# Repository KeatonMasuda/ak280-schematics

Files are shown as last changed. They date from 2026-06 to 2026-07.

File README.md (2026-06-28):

# ak280-schematics

[Japanese README is here](README.ja.md)

This repository contains the schematic for the AK-280 audio amplifier purchased from Amazon, created by tracing the printed patterns and components. The schematic is created using KiCad.

<p align="center">
  <a href="images/ak280-schematic.pdf">
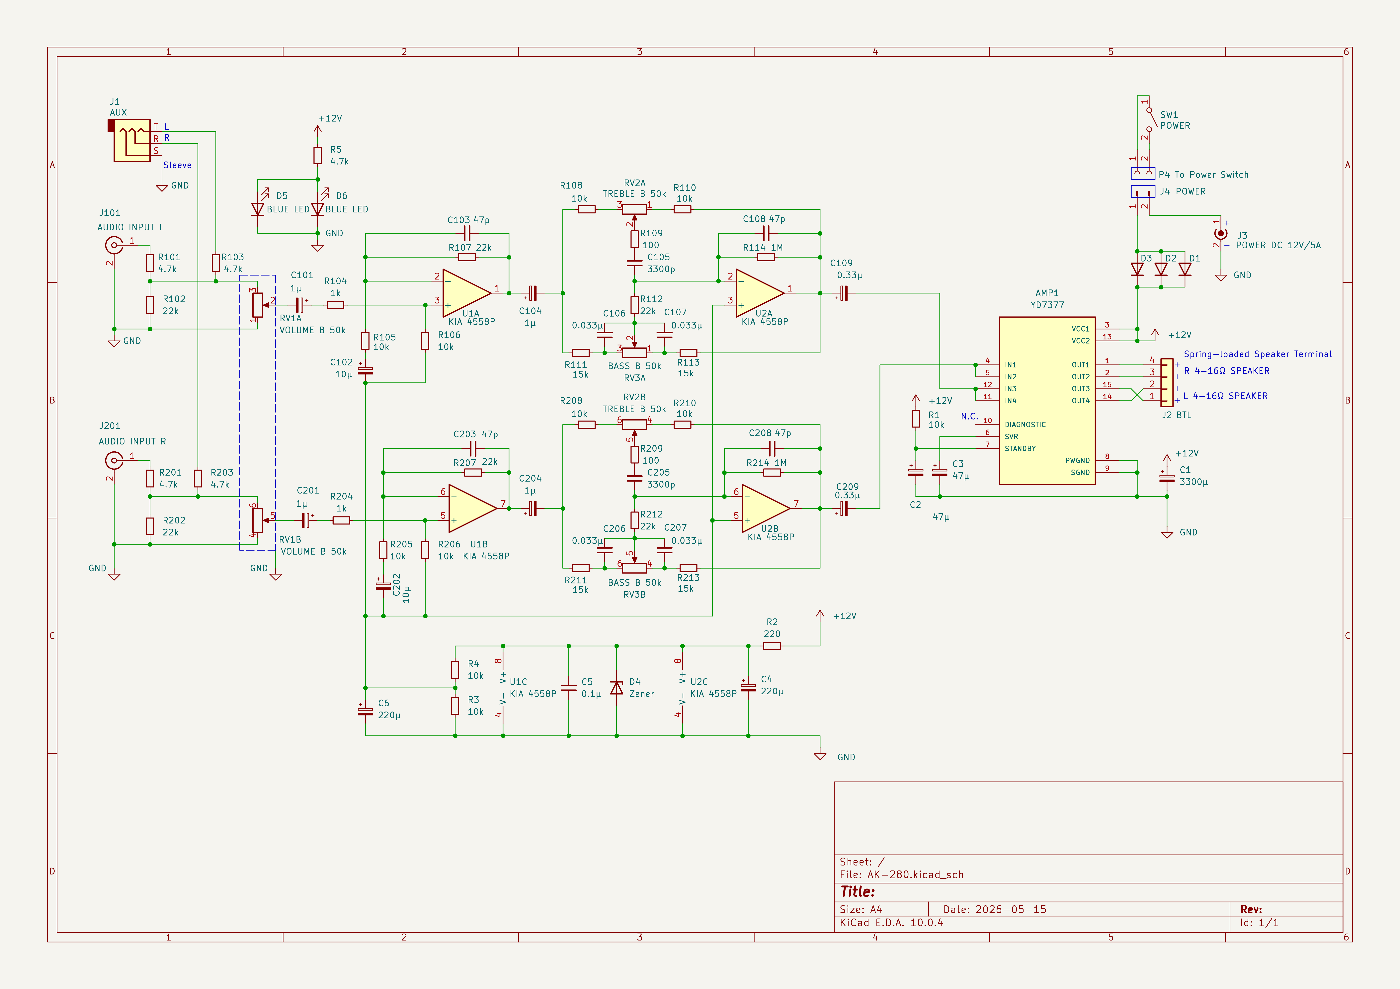
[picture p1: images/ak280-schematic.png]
    
  </a><br>
  Figure 1: AK-280 schematic(clock to PDF)
</p>

<table style="width: 100%; border: none;">
  <tr>
    <td style="width: 50%; text-align: center; border: none;">
      <br>
      Figure 2: AK-280 close-up
    </td>
    <td style="width: 50%; text-align: center; border: none;">
      <br>
      Figure 3: AK-280 SP system
    </td>
  </tr>
  <tr>
    <td style="width: 50%; text-align: center; border: none;">
      <br>
      Figure 4: PCB Component side with reference numbers
    </td>
    <td style="width: 50%; text-align: center; border: none;">
      <br>
      Figure 5: PCB Solder side with reference numbers
    </td>
  </tr>
  <tr>
    <td style="width: 50%; text-align: center; border: none;">
      <br>
      Figure 6: PCB Solder side with reference numbers (mirrored)
    </td>
    <td style="width: 50%; text-align: center; border: none;">
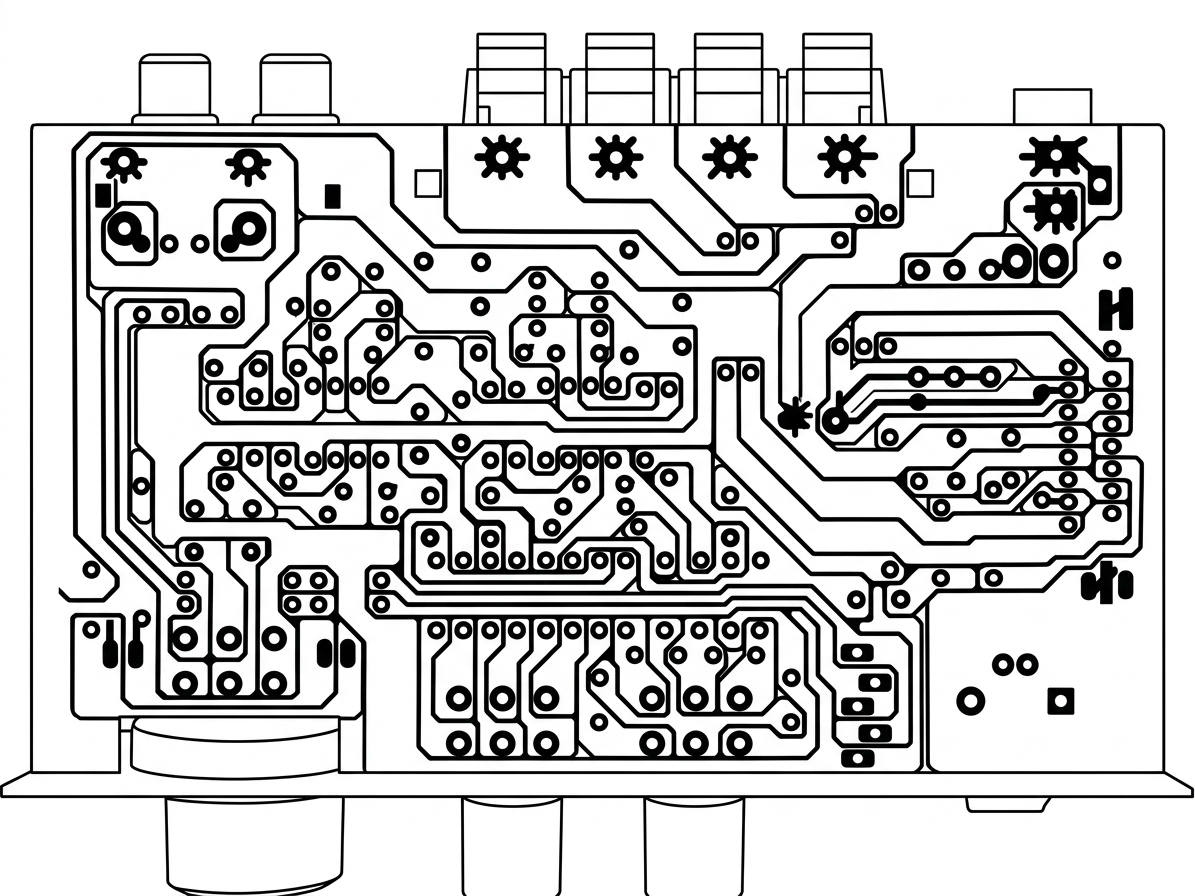
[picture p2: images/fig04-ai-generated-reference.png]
      <br>
      Figure 7: AI-generated reference
    </td>
  </tr>
</table>

## Project Objective
This project was created for personal hobby purposes only. There is no specific intended purpose or goal.

## Directory Structure

    ak280-schematics/
    ├── hardware/
    │   ├── AK-280.kicad_pro
    │   └── AK-280.kicad_sch
    ├── images/
    │   ├── ak280-photo.png
    │   ├── ak280-schematic.pdf
    │   ├── ak280-schematic.png
    │   ├── ak280-system-photo.png
    │   ├── fig01-topside-with-refno.png
    │   ├── fig01-topside-with-refno.zip
    │   ├── fig02-bottomside-with-refno-org.png
    │   ├── fig02-bottomside-with-refno-org.zip
    │   ├── fig03-bottomside-with-refno-mirror.png
    │   ├── fig03-bottomside-with-refno-mirror.zip
    │   └── fig04-ai-generated-reference.png
    ├── LICENSE
    ├── README.ja.md
    └── README.md

## File Descriptions

* **hardware/**: Contains all KiCad schematic files and design data.
* **images/**: Contains the following circuit diagrams and related reference materials:
    * **ak280-schematic.pdf**: Circuit schematic (PDF file)
    * **ak280-schematic.png**: Circuit schematic (PNG file)
    * **ak280-photo.png**: Close-up photo of AK-280
    * **ak280-system-photo.png**: AK-280 SP system photo
    * **fig01-topside-with-refno.png**: Top-side photo with circuit reference numbers (For viewing)
    * **fig01-topside-with-refno.zip**: Top-side photo with circuit reference numbers (GIMP source data)
    * **fig02-bottomside-with-refno-org.png**: Bottom-side photo with circuit reference numbers (Original, for viewing)
    * **fig02-bottomside-with-refno-org.zip**: Bottom-side photo with circuit reference numbers (Original, GIMP source data)
    * **fig03-bottomside-with-refno-mirror.png**: Bottom-side photo with circuit reference numbers (Mirrored, for viewing)
    * **fig03-bottomside-with-refno-mirror.zip**: Bottom-side photo with circuit reference numbers (Mirrored, GIMP source data)
    * **fig04-ai-generated-reference.png**: Pattern diagram generated by AI and verified by visual inspection.
* **LICENSE**: Project license information.
* **README.ja.md**: Detailed project description in Japanese.
* **README.md**: Detailed project description in English (this file).

## Environment
* **KiCad**: 10.0.4
* **GIMP**: 3.2.4

## Usage

* **View Schematic**: Refer to `images/ak280-schematic.pdf`.
* **View Component Reference Numbers**: Refer to `images/fig01-topside-with-refno.png` and `images/fig02-bottomside-with-refno-org.png`.
* **Edit Schematic**: Launch KiCad and open `hardware/AK-280.kicad_pro`.
* **Edit Component Reference Numbers**: Extract `images/fig01-topside-with-refno.zip`, `images/fig02-bottomside-with-refno-org.zip`, or `images/fig03-bottomside-with-refno-mirror.zip` and open them with GIMP.

## Disclaimer
The schematics in this repository were created based on visual inspection of the actual board . While every effort has been made to ensure accuracy, the integrity of the netlist is not 100% guaranteed. The author assumes no responsibility or liability for any damage, accidents, unforeseen malfunctions, or other losses resulting from the use of this data. Please use at your own risk.

## Acknowledgments
* The TDA7377 KiCad symbol used in this project is provided by Snapmagic (https://www.snapmagic.com/)

## License
This project is licensed under the MIT License. See the [LICENSE](LICENSE) file for details.

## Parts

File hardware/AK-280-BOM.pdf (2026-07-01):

AK-280

# ページ 1

Reference Qty MANUFACTURER | Value | Voltage Wattage Type
AMP1 | 1 | Wuxi Youda Electronics YD7377
C1 | 1 | 3300μ | 16V | Aluminum Electrolytic (Standard)
C2 | 1 | 47μ | 25V | Aluminum Electrolytic (Standard)
C3 | 1 | 47μ | 25V | Aluminum Electrolytic (Standard)
C4 | 1 | 220μ | 16V | Aluminum Electrolytic (Standard)
C5 | 1 | 0.1μ | | Ceramic Capacitor (X7R)
C6 | 1 | 220μ | 16V | Aluminum Electrolytic (Standard)
C101 | 1 | 1μ | 50V | Aluminum Electrolytic (Low ESR)
C102 | 1 | 10μ | 50V | Aluminum Electrolytic (Low ESR)
C103 | 1 | 47p | | Ceramic Capacitor (C0G)
C104 | 1 | 1μ | 50V | Aluminum Electrolytic (Low ESR)
C105 | 1 | 3300p | | Film Capacitor
C106 | 1 | 0.033μ | | Film Capacitor
C107 | 1 | 0.033μ | | Film Capacitor
C108 | 1 | 47p | | Ceramic Capacitor (C0G)
C109 | 1 | 0.33μ | 50V | Aluminum Electrolytic (Low ESR)
C201 | 1 | 1μ | 50V | Aluminum Electrolytic (Low ESR)
C202 | 1 | 10μ | 50V | Aluminum Electrolytic (Low ESR)
C203 | 1 | 47p | | Ceramic Capacitor (C0G)
C204 | 1 | 1μ | 50V | Aluminum Electrolytic (Low ESR)
C205 | 1 | 3300p | | Film Capacitor
C206 | 1 | 0.033μ | | Film Capacitor
C207 | 1 | 0.033μ | | Film Capacitor
C208 | 1 | 47p | | Ceramic Capacitor (C0G)
C209 | 1 | 0.33μ | 50V | Aluminum Electrolytic (Low ESR)
D1 | 1 | 1N5400
D2 | 1 | 1N5400
D3 | 1 | 1N5400
D4 | 1 | Zener | 9.1V
D5 | 1 | BLUE LED
D6 | 1 | BLUE LED
J1 | 1 | AUX
J2 | 1 | BTL

AK-280

# ページ

2

J3

1 | POWER DC 12V/5A
J4
1 | POWER
J101
1 | AUDIO INPUT L
J201
1 | AUDIO INPUT R
P4
1 | To Power Switch
R1
1 | 10k | 1/4W
R2
1 | 220 | 1/2W
R3
1 | 10k | 1/4W
R4
1 | 10k | 1/4W
R5
1 | 4.7k | 1/4W
R101
1 | 4.7k | 1/4W
R102
1 | 22k | 1/4W
R103
1 | 4.7k | 1/4W
R104
1 | 1k | 1/4W
R105
1 | 10k | 1/4W
R106
1 | 10k | 1/4W
R107
1 | 22k | 1/4W
R108
1 | 10k | 1/4W
R109
1 | 100 | 1/4W
R110
1 | 10k | 1/4W
R111
1 | 15k | 1/4W
R112
1 | 22k | 1/4W
R113
1 | 15k | 1/4W
R114
1 | 1M | 1/4W
R201
1 | 4.7k | 1/4W
R202
1 | 22k | 1/4W
R203
1 | 4.7k | 1/4W
R204
1 | 1k | 1/4W
R205
1 | 10k | 1/4W
R206
1 | 10k | 1/4W
R207
1 | 22k | 1/4W
R208
1 | 10k | 1/4W
R209
1 | 100 | 1/4W
R210
1 | 10k | 1/4W

AK-280

# ページ 3

R211 | 1 | 15k | 1/4W
R212 | 1 | 22k | 1/4W
R213 | 1 | 15k | 1/4W
R214 | 1 | 1M | 1/4W
RV1 | 1 | VOLUME B 50k
RV2 | 1 | TREBLE B 50k
RV3 | 1 | BASS B 50k
SW1 | 1 | POWER
U1 | 1 | Korea Electronics | KIA 4558P
U2 | 1 | Korea Electronics | KIA 4558P

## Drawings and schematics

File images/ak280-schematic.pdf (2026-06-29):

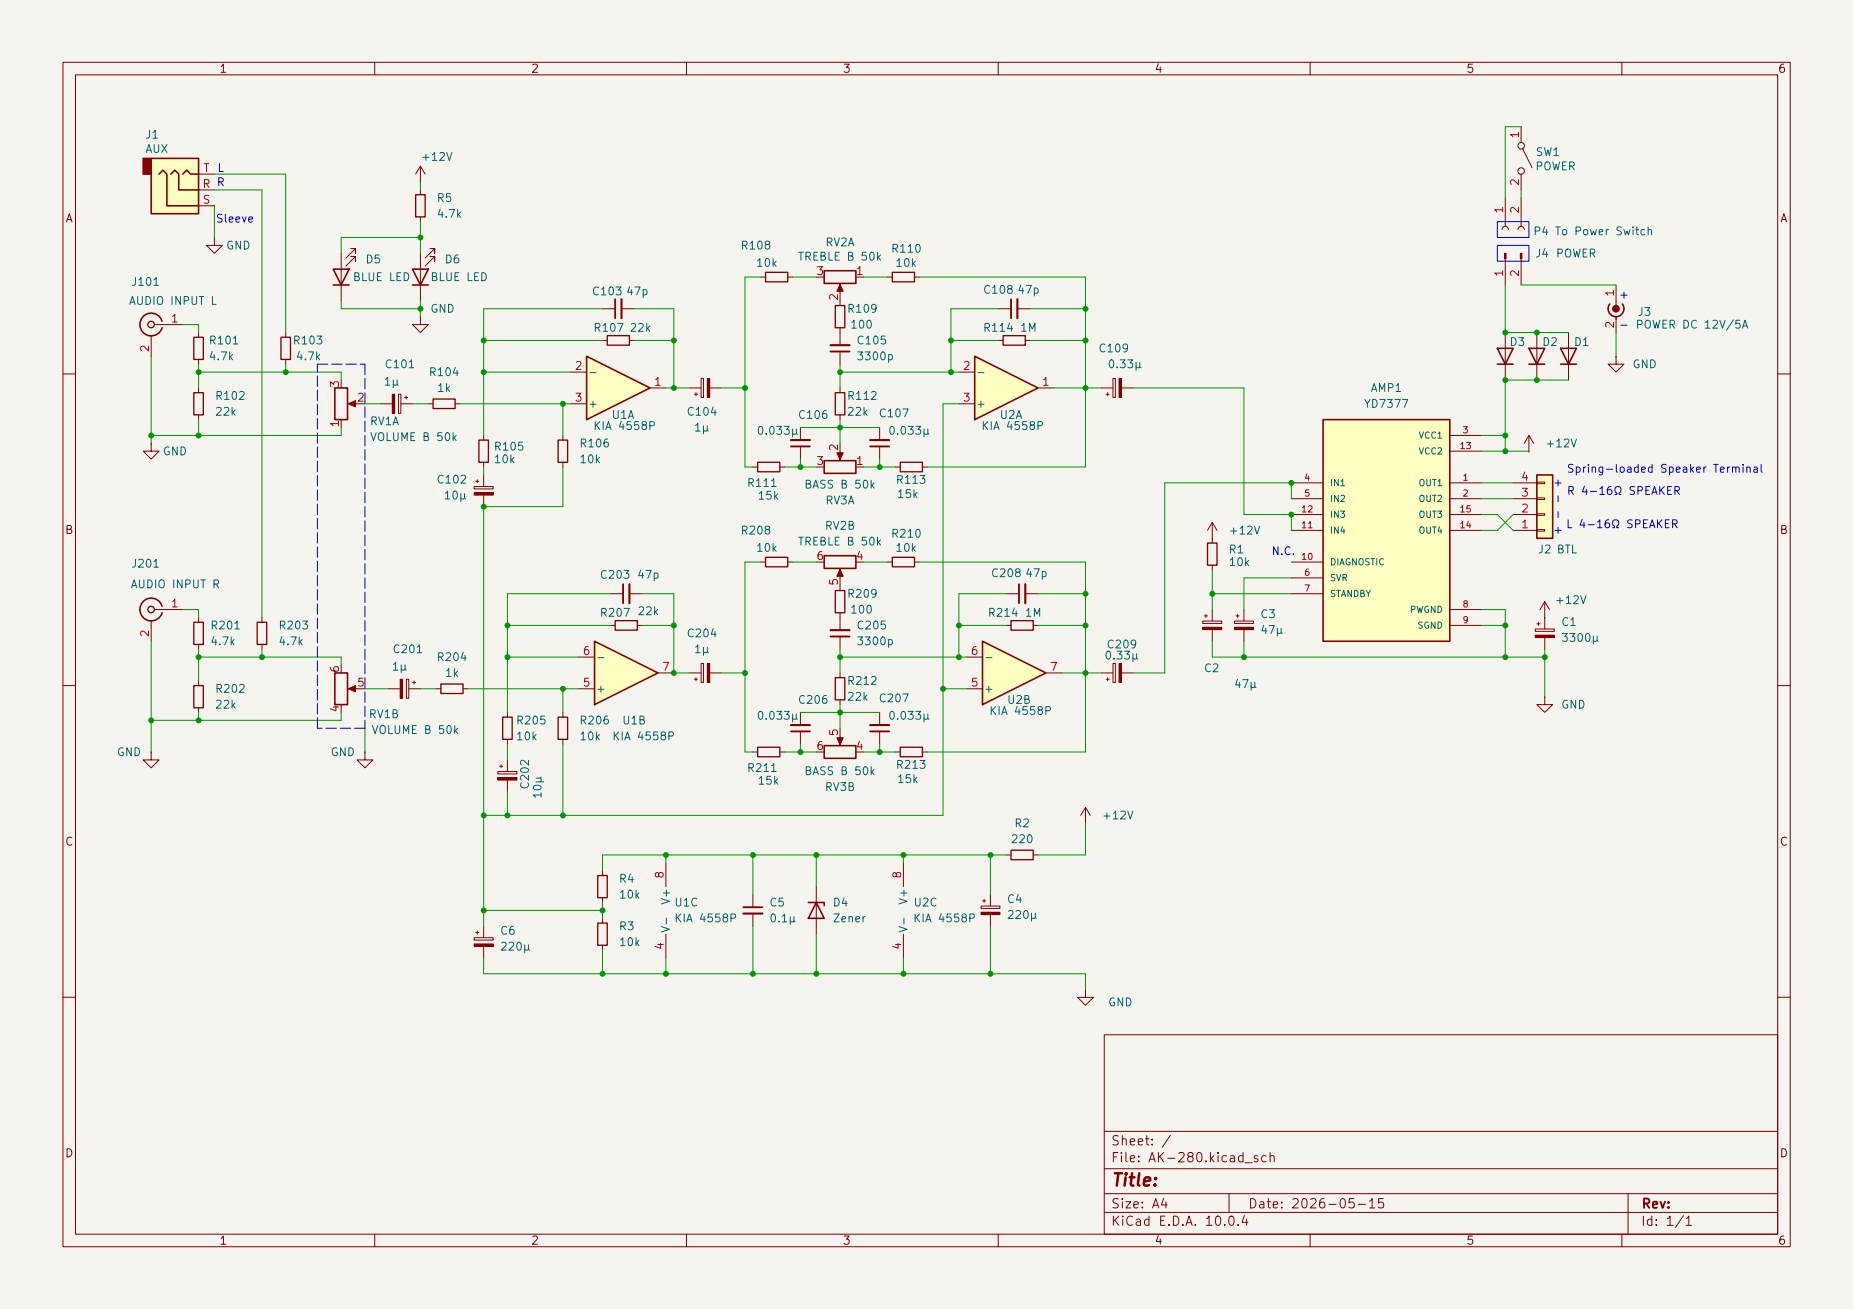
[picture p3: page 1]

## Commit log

2026-06-27 Add ak280-schematic.pdf
2026-06-27 Add hardware & images files.
    [AK-280.kicad_sch]
2026-06-28 Add Japanese README for AK-280 schematics
    This update includes the Japanese README file with detailed project information, images, and usage instructions for the AK-280 audio amplifier schematics.
2026-06-29 Add files via upload
    Add "C6" & BOM
